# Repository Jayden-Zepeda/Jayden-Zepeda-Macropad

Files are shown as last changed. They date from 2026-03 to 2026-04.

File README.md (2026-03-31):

# ZepedaPad

> A custom 14-key macropad with dual rotary encoders, per-key RGB lighting, and an OLED display — built on the Seeed XIAO RP2040 with QMK firmware.

<p align="center">
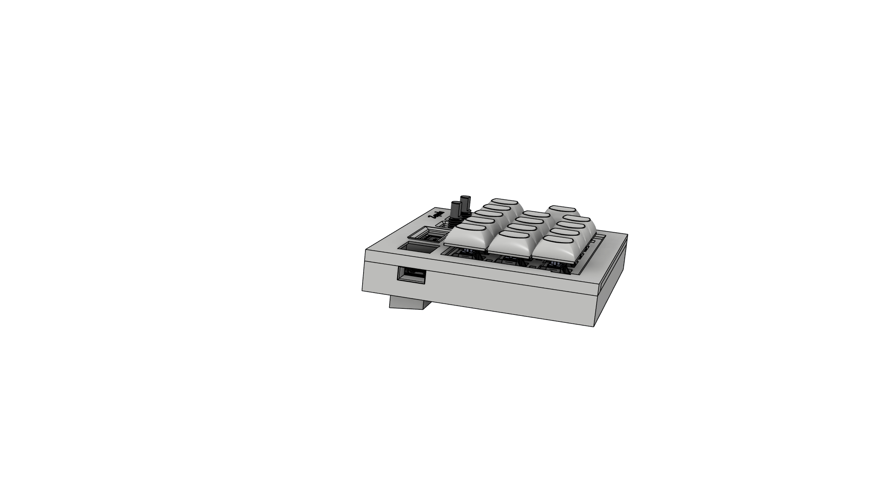
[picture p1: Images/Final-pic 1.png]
Zepeda Macropad Top View
  
</p>

---

## 📖 Overview

The **Zepeda** is a compact, handcrafted macropad designed for productivity and personalization. It features 14 MX-style switches arranged in a 3×4 grid (plus a dedicated column), two EC11 rotary encoders for scrolling or volume control, individually addressable SK6812 MINI-E RGB LEDs under every key, and a 0.91" OLED display for live feedback — all driven by a Seeed XIAO RP2040 and QMK firmware.

The key matrix is read through a **74HC165 shift register**, keeping GPIO usage minimal while supporting full anti-ghosting via 1N4148 diodes. The entire build fits inside a custom 3-part 3D-printed case secured with heatset inserts and M3 screws.

PCB is designed through KICAD and the case is designed in Autodesk Fusion-FREE.

---

## 🖼️ Screenshots

### 3D Render

<p align="center">
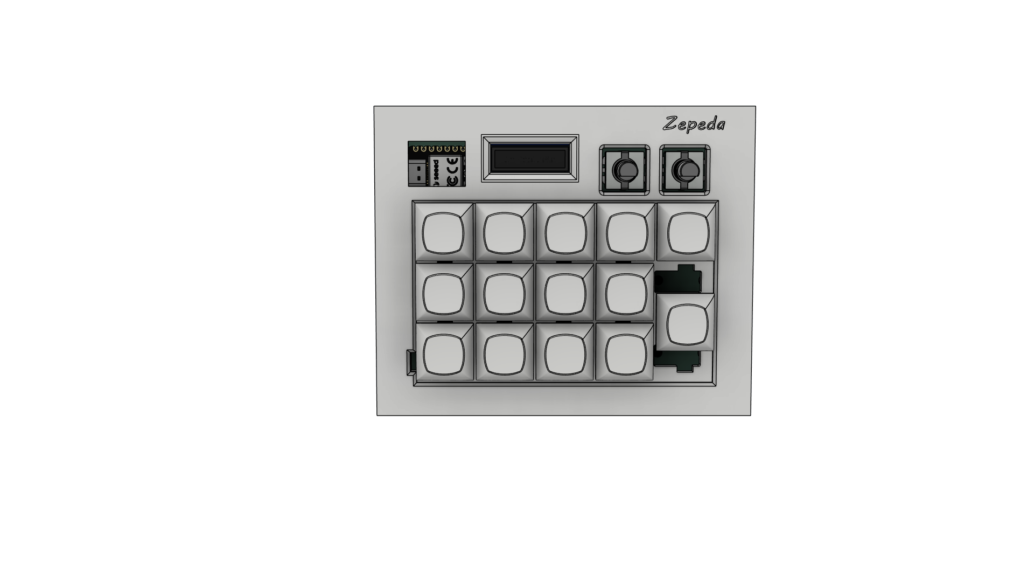
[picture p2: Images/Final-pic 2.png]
Top-down render
  
  <br/><em>Top-down view</em>
</p>

<p align="center">
  Isometric render
  <br/><em>Isometric view showing case depth and USB cutout</em>
</p>

---

### Schematic

> Full schematic showing the XIAO RP2040, 74HC165 shift register, LED chain, diode matrix, rotary encoders, and OLED connector.

<p align="center">
  Schematic
  <br/><em>KiCad schematic — macropad.kicad_sch</em>
</p>

---

### PCB Layout

<p align="center">
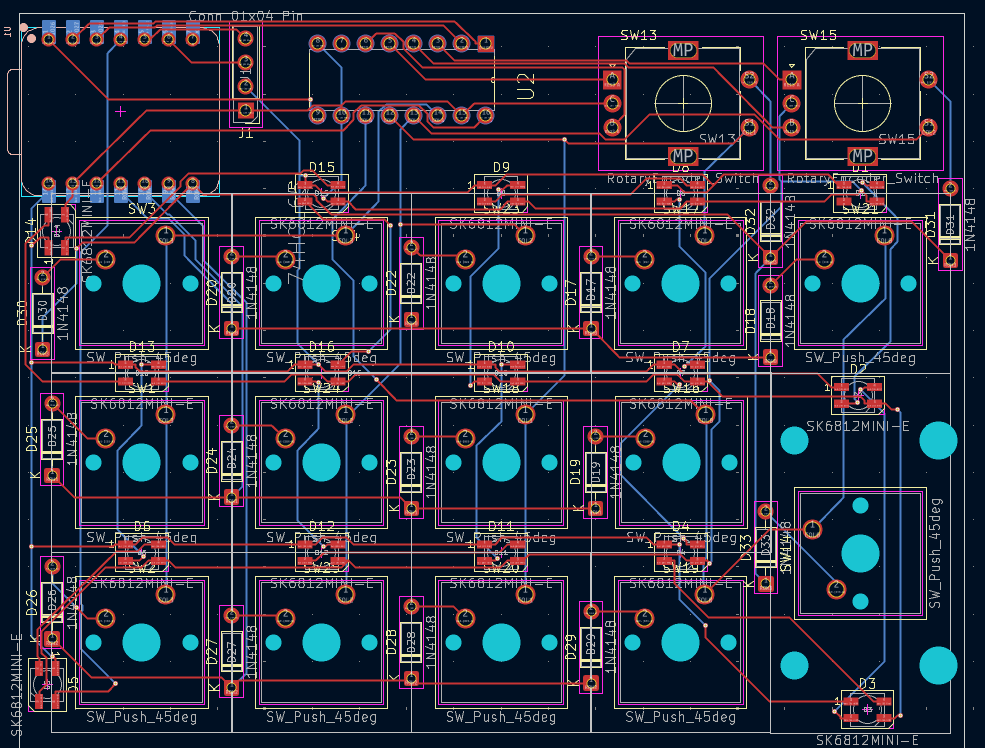
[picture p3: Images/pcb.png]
PCB Layout
  
  <br/><em>KiCad PCB layout — red/blue layers, switch footprints, and LED positions visible</em>
</p>

---

### Case

<p align="center">
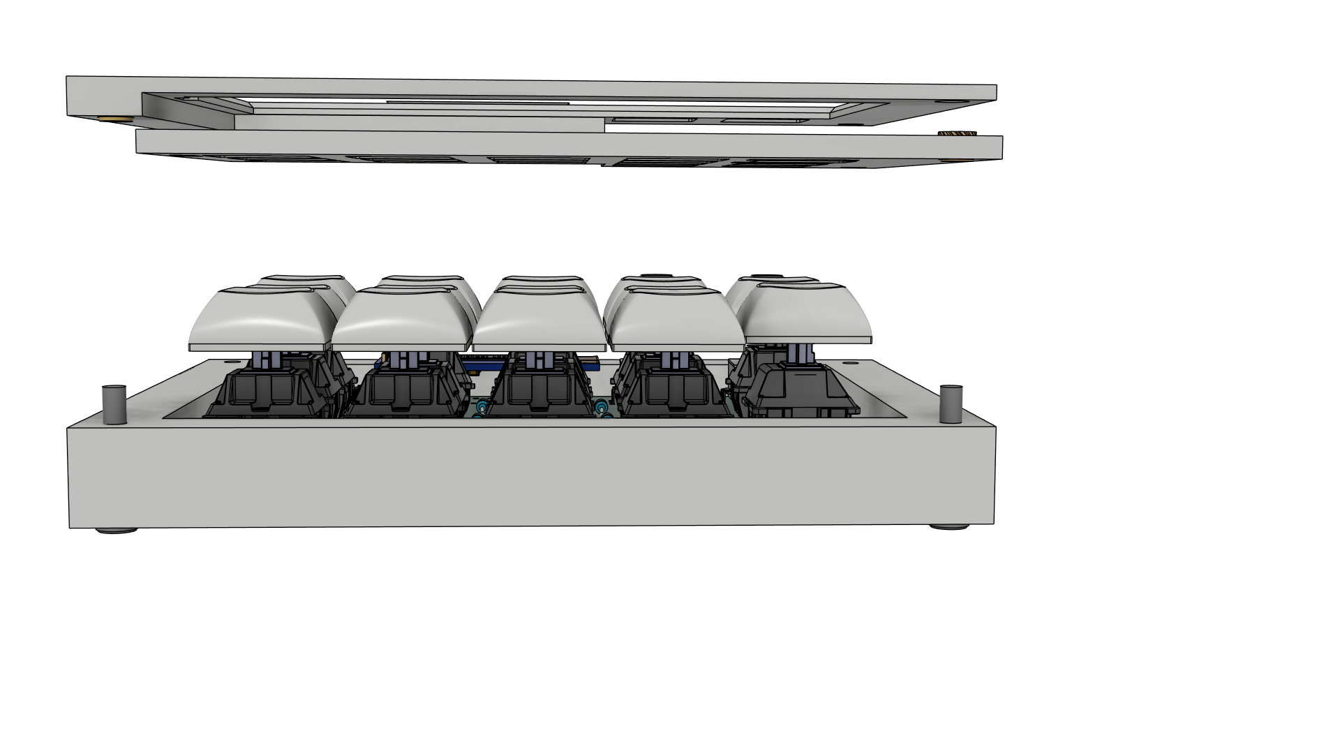
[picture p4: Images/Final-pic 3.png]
Case isometric
  
  <br/><em>3-part 3D-printed enclosure with heatset inserts. The PCB sits inside the bottom shell; the top plate exposes keycaps, encoders, and the OLED. A middle layer sandwiches everything together. Screws are enter from bottom, they go in 2mm freely and then left side screws all the way into the heatset insterts that are in the top shell while, the right side screws does a very similar thing except the heatset insterts are 1mm in the top shell and 3mm in the middle shell.</em>
</p>

The case consists of three printed parts(created in Autodesk Fusion-FREE) :
- **Bottom shell** — holds the PCB
- **Middle frame / plate** — key switch mounting plate
- **Top accent** — surrounds the OLED and encoder knobs

All three parts are secured with **4× M3×16mm screws** threading into **4× M3×5mm×4mm heatset inserts** pressed into the top/middle shell.

---

## 🧰 Bill of Materials (BOM)

| Qty | Part | Notes |
|-----|---|---|
| 1 | Seeed XIAO RP2040 | Microcontroller (unsoldered) |
| 1 | 74HC165 Shift Register | Through-hole DIP-16 |
| 16 | SK6812 MINI-E LEDs | Per-key addressable RGB |
| 16 | 1N4148 Diodes | Through-hole, for key matrix |
| 14 | MX-Style Switches | Any MX-compatible switch |
| 14 | White Blank DSA Keycaps | 1u, blank |
| 2 | EC11 Rotary Encoders | With push-click |
| 1 | 0.91" OLED Display | I2C, SSD1306 |
| 1 | 3D-Printed Case | 3 printed parts |
| 4 | M3×16mm Screws | Case assembly |
| 4 | M3×5mm×4mm Heatset Inserts | Press-fit into top/middle shell |

---

## ⚡ Firmware

This macropad runs **QMK Firmware**. The 74HC165 shift register is used to read the key matrix, and the SK6812 MINI-E LEDs are driven via QMK's RGB Matrix feature. Created a full keyboard and keymap layout from scratch. Included in firmware folder(macropad).                                    

Features:
-Copy/Paste Key: First click is copy-second is paste, with an led and OLED display to show your status.
-Mute/Unmute Key: Led and OLED display to show your status
-4 Different Layers: Base, Media, Gaming, and CFG -- w/ led status

To build and flash:

```bash
qmk compile -kb macropad -km default
qmk flash -kb macropad -km default
```

Put the XIAO RP2040 into bootloader mode by holding **BOOT** while plugging in USB (or double-tapping RST).

---

## 🔧 Build Notes

- Solder **heatset inserts first** before assembling the case
- Flash QMK firmware onto the XIAO RP2040 **before** soldering it to the board
- The LED chain is daisy-chained: DOUT of each SK6812 connects to DIN of the next
- Diodes are oriented with the **cathode (K) toward the row line** — check markings before soldering
- The 74HC165's `~PL`, `CP`, and `Q7` lines connect to GPIO26, GPIO27, and GPIO28 on the XIAO respectively

---

## 📁 Repository Structure

```
Jayden-Zepeda-Macropad/
├── pcb/               # KiCad project files (.kicad_sch, .kicad_pcb)
├── case/              # 3D print files (.step / .stl)
├── firmware/          # QMK keymap and config
├── images/            # Images
├── production/            # Files for production
└── README.md
```

---

*Made with ❤️ as part of [Hack Club's PCB program](https://hackclub.com/)*

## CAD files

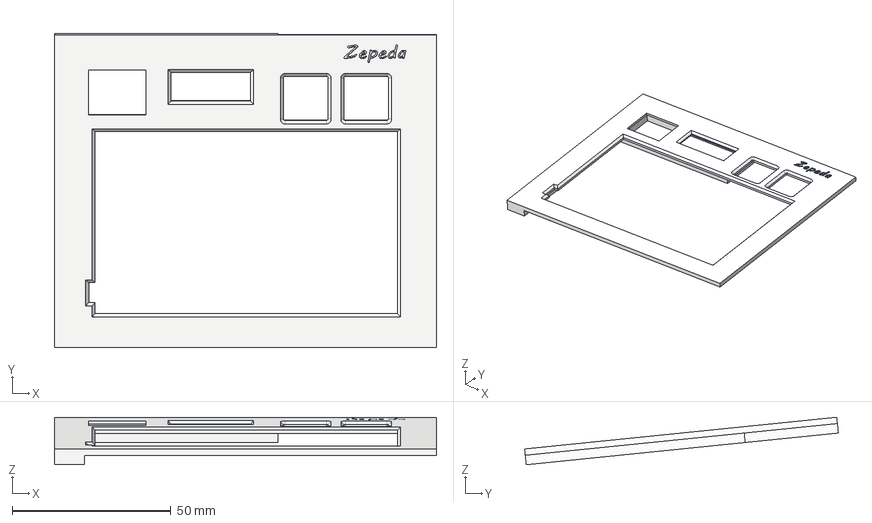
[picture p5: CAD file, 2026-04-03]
Production/Top.step
120.4 x 98.9 x 15.0 mm

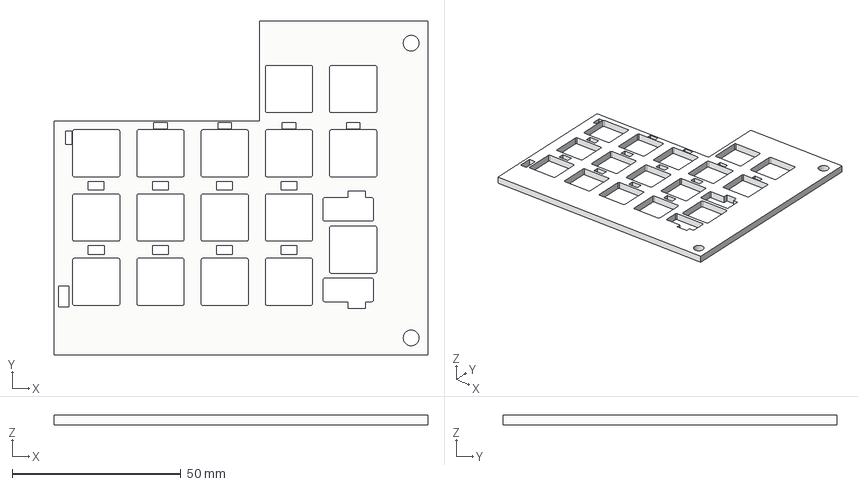
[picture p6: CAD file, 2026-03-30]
Production/Middle.step
110.9 x 98.9 x 3.00 mm

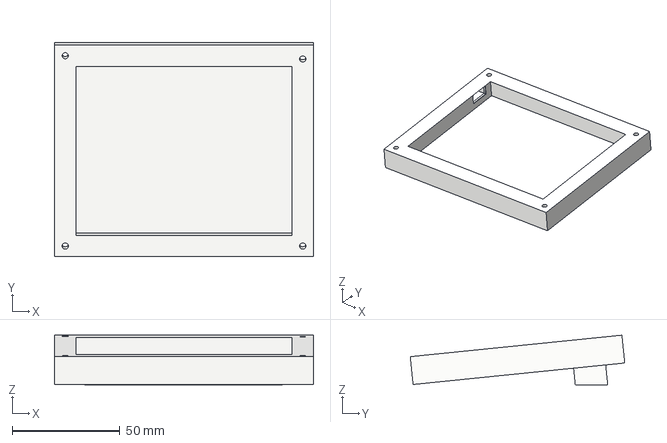
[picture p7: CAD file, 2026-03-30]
Production/Bottom.step
120.4 x 99.7 x 23.1 mm

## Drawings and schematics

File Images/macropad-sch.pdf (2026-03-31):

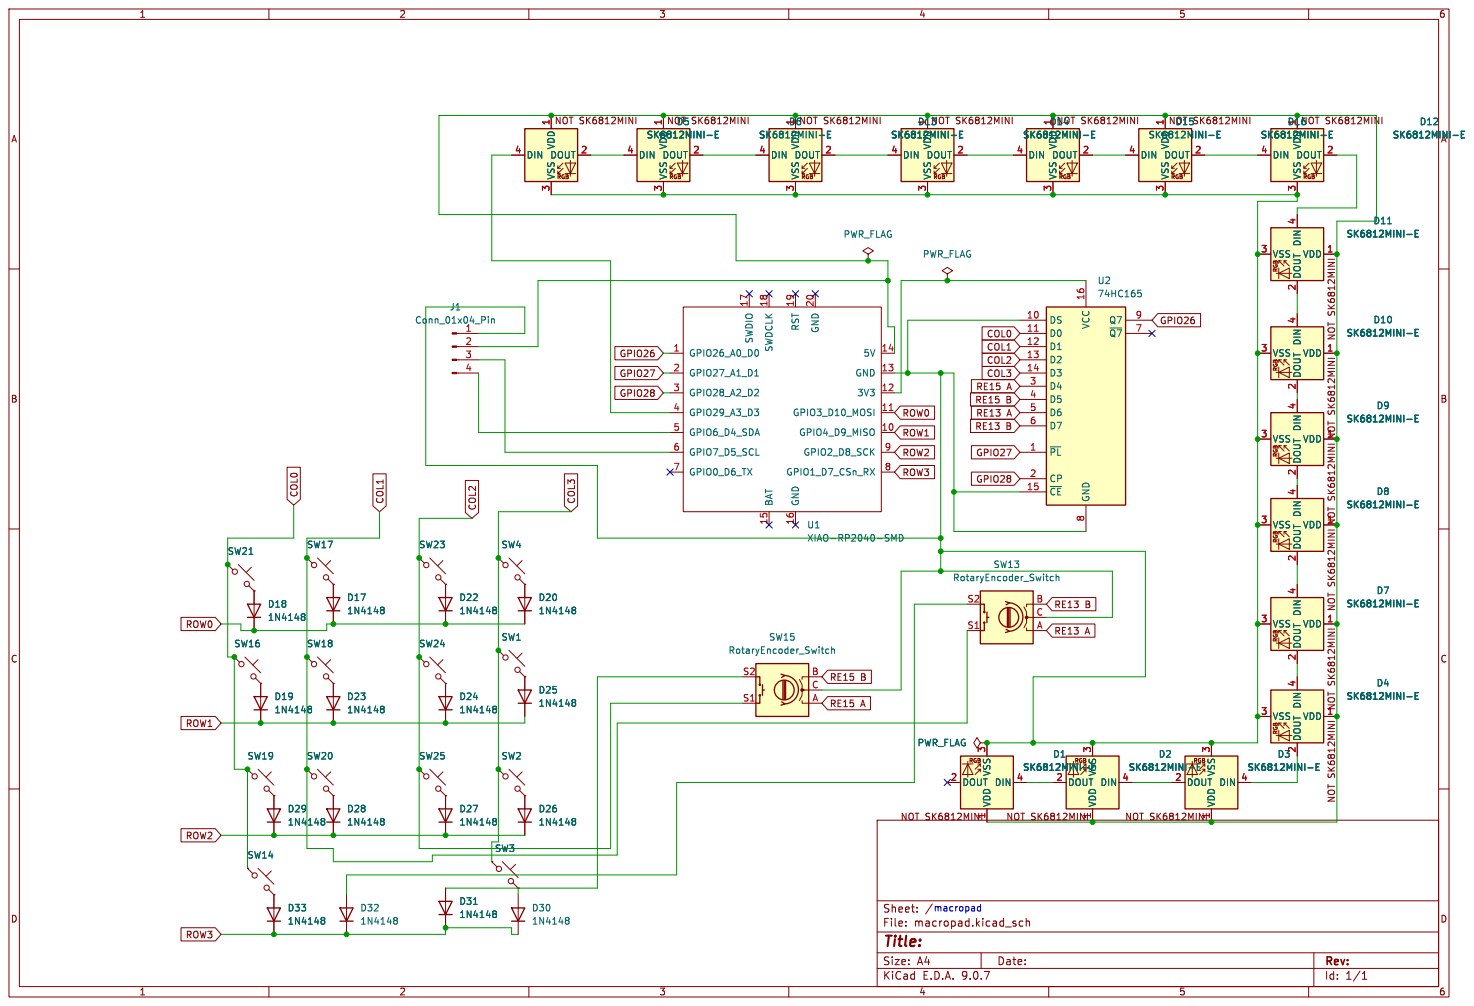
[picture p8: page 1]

3 DOUT 2 D6 SK6812MINI-E GPIO26_A0_D0 1 GPIO27_A1_D1 2 GPIO28_A2_D2 3 GPIO29_A3_D3 4 GPIO6_D4_SDA 5 GPIO7_D5_SCL 6 GPIO0_D6_TX 7 SWDIO 17 SWDCLK 18 BAT 15 RST 19 GND 16 GND 20

3 DOUT 2 D12 SK6812MINI-E RGB NOT SK6812MINI DIN

Id: 1/1 Title: File: macropad.kicad_sch Sheet: / PWR_FLAG

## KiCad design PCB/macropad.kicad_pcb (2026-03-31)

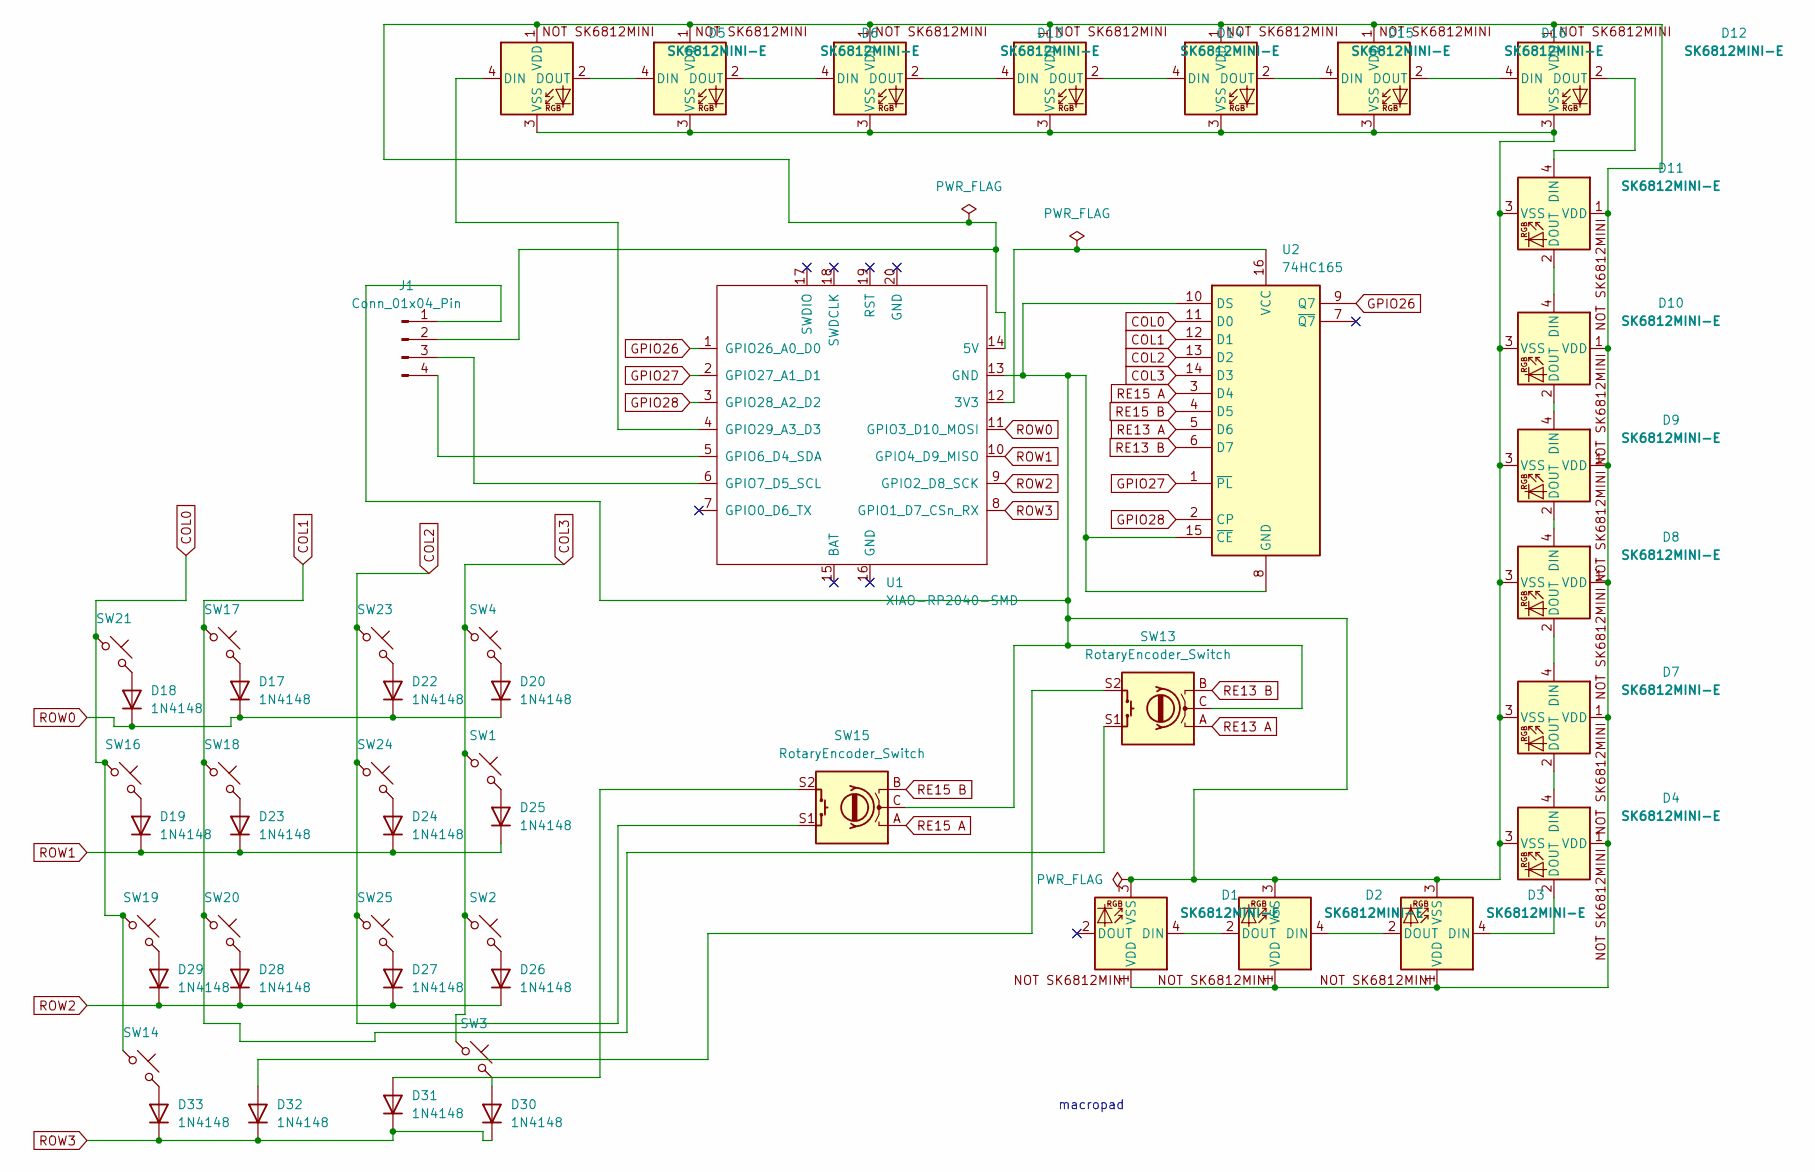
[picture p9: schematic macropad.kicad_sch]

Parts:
D1, D2, D3, D4, D5, D6, D7, D8, D9, D10, D11, D12, D13, D14, D15, D16: SK6812MINI-E; LED_SK6812MINI_PLCC4_3.5x3.5mm_P1.75mm
D17, D18, D19, D20, D22, D23, D24, D25, D26, D27, D28, D29, D30, D31, D32, D33: 1N4148; D_DO-35_SOD27_P7.62mm_Horizontal
J1: Conn_01x04_Pin; PinHeader_1x04_P2.54mm_Vertical
SW1, SW2, SW3, SW4, SW16, SW17, SW18, SW19, SW20, SW21, SW23, SW24, SW25: SW_Push_45deg; SW_Cherry_MX_1.00u_PCB
SW13, SW15: RotaryEncoder_Switch; RotaryEncoder_Alps_EC11E-Switch_Vertical_H20mm
SW14: SW_Push_45deg; SW_Cherry_MX_2.00u_PCB
U1: XIAO-RP2040-SMD; XIAO-RP2040-DIP
U2: 74HC165; DIP254P762X420-16

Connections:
COL0: SW14.1, SW16.1, SW19.1, SW21.1, U2.11 (D0)
COL1: SW13.S1, SW17.1, SW18.1, SW20.1, U2.12 (D1)
COL2: SW15.S1, SW23.1, SW24.1, SW25.1, U2.13 (D2)
COL3: SW1.1, SW2.1, SW3.1, SW4.1, U2.14 (D3)
GPIO26: U1.1 (GPIO26_A0_D0), U2.9 (Q7)
GPIO27: U1.2 (GPIO27_A1_D1), U2.1 (~PL)
GPIO28: U1.3 (GPIO28_A2_D2), U2.2 (CP)
unnamed: D1.4 (DIN), D2.2 (DOUT)
unnamed: D1.1 (VDD), D2.1 (VDD), D3.1 (VDD), D4.1 (VDD), D5.1 (VDD), D6.1 (VDD), D7.1 (VDD), D8.1 (VDD), D9.1 (VDD), D10.1 (VDD), D11.1 (VDD), D12.1 (VDD), D13.1 (VDD), D14.1 (VDD), D15.1 (VDD), D16.1 (VDD), J1.2, U1.14 (5V)
unnamed: D1.3 (VSS), D2.3 (VSS), D3.3 (VSS), D4.3 (VSS), D5.3 (VSS), D6.3 (VSS), D7.3 (VSS), D8.3 (VSS), D9.3 (VSS), D10.3 (VSS), D11.3 (VSS), D12.3 (VSS), D13.3 (VSS), D14.3 (VSS), D15.3 (VSS), D16.3 (VSS), J1.1, SW13.C, SW15.C, U1.13 (GND), U2.8 (GND), U2.10 (DS), U2.15 (~CE)
unnamed: D2.4 (DIN), D3.2 (DOUT)
unnamed: D3.4 (DIN), D4.2 (DOUT)
unnamed: D4.4 (DIN), D7.2 (DOUT)
unnamed: D5.4 (DIN), U1.4 (GPIO29_A3_D3)
unnamed: D5.2 (DOUT), D6.4 (DIN)
unnamed: D7.4 (DIN), D8.2 (DOUT)
unnamed: D8.4 (DIN), D9.2 (DOUT)
unnamed: D10.4 (DIN), D11.2 (DOUT)
unnamed: D9.4 (DIN), D10.2 (DOUT)
unnamed: D11.4 (DIN), D12.2 (DOUT)
unnamed: D12.4 (DIN), D16.2 (DOUT)
unnamed: D6.2 (DOUT), D13.4 (DIN)
unnamed: D13.2 (DOUT), D14.4 (DIN)
unnamed: D14.2 (DOUT), D15.4 (DIN)
unnamed: D15.2 (DOUT), D16.4 (DIN)
unnamed: D17.2 (A), SW17.2
unnamed: D18.2 (A), SW21.2
unnamed: D19.2 (A), SW16.2
unnamed: D20.2 (A), SW4.2
unnamed: D22.2 (A), SW23.2
unnamed: D23.2 (A), SW18.2
unnamed: D24.2 (A), SW24.2
unnamed: D25.2 (A), SW1.2
unnamed: D26.2 (A), SW2.2
unnamed: D27.2 (A), SW25.2
unnamed: D28.2 (A), SW20.2
unnamed: D29.2 (A), SW19.2
unnamed: D30.2 (A), SW3.2
unnamed: D31.2 (A), SW15.S2
unnamed: D32.2 (A), SW13.S2
unnamed: D33.2 (A), SW14.2
unnamed: J1.3, U1.6 (GPIO7_D5_SCL)
unnamed: J1.4, U1.5 (GPIO6_D4_SDA)
unnamed: U1.12 (3V3), U2.16 (VCC)
RE13 A: SW13.A, U2.5 (D6)
RE13 B: SW13.B, U2.6 (D7)
RE15 A: SW15.A, U2.3 (D4)
RE15 B: SW15.B, U2.4 (D5)
ROW0: D17.1 (K), D18.1 (K), D20.1 (K), D22.1 (K), U1.11 (GPIO3_D10_MOSI)
ROW1: D19.1 (K), D23.1 (K), D24.1 (K), D25.1 (K), U1.10 (GPIO4_D9_MISO)
ROW2: D26.1 (K), D27.1 (K), D28.1 (K), D29.1 (K), U1.9 (GPIO2_D8_SCK)
ROW3: D30.1 (K), D31.1 (K), D32.1 (K), D33.1 (K), U1.8 (GPIO1_D7_CSn_RX)

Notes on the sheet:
macropad

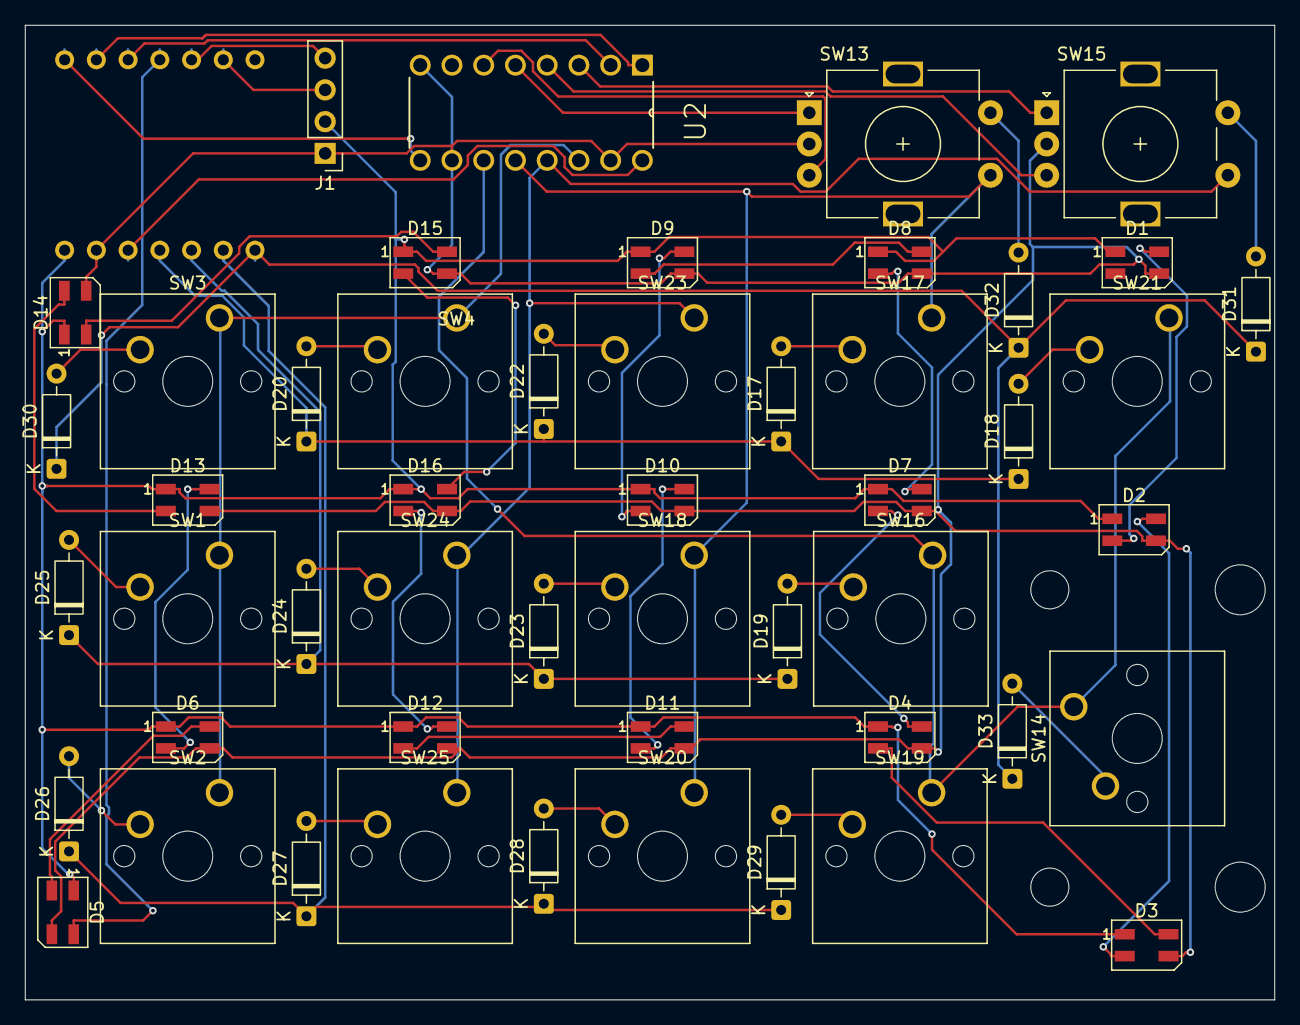
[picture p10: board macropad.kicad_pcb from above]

Board: 2 copper layers, 100.0 x 78.0 mm, 51 parts (1 on the bottom side), 52 nets.

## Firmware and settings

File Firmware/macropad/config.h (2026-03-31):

#pragma once

// ── Matrix ────────────────────────────────────────────────────────────────────
#define MATRIX_ROWS 4
#define MATRIX_COLS 4
#define MATRIX_ROW_PINS { GP3, GP4, GP2, GP1 }

// ── 74HC165 shift register ────────────────────────────────────────────────────
//   GP27=~PL(latch)  GP28=CP(clock)  GP26=Q7(data)
//   Bits: [7]=ENC0-B [6]=ENC0-A [5]=ENC1-B [4]=ENC1-A [3]=COL3 [2]=COL2 [1]=COL1 [0]=COL0
#define SHIFT_REG_PL   GP27
#define SHIFT_REG_CLK  GP28
#define SHIFT_REG_DATA GP26

// ── Encoders ──────────────────────────────────────────────────────────────────
#define NUM_ENCODERS       2
#define ENCODER_RESOLUTION 4

// ── Timings ───────────────────────────────────────────────────────────────────
#define DEBOUNCE     5
#define TAPPING_TERM 200

// ── I2C (for OLED — connects via J1: GP6=SDA, GP7=SCL) ───────────────────────
#define I2C_DRIVER   I2CD1
#define I2C1_SDA_PIN GP6
#define I2C1_SCL_PIN GP7

// ── OLED (SSD1306 128x32) ─────────────────────────────────────────────────────
#define OLED_DISPLAY_128X32
#define OLED_TIMEOUT     60000   // turn off after 60s of no activity (ms)
#define OLED_BRIGHTNESS  200

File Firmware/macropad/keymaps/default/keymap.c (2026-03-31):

#include QMK_KEYBOARD_H

// ═══════════════════════════════════════════════════════════════════════════════
//  MACROPAD KEYMAP + OLED
// ═══════════════════════════════════════════════════════════════════════════════
//
//  OLED (128x32, connects to J1 on the board via GP6=SDA / GP7=SCL):
//
//   ┌─────────────────────────────────────────┐
//   │ PRODUCTIVITY            52 wpm           │  layer name + WPM
//   │ VOL  [████████░░]  80%  ♪               │  volume bar + speaker icon
//   │ MIC  [ LIVE  ]   CLIP  [READY]          │  mic & clipboard status
//   │ Undo  Redo   Cut   Copy/Paste            │  key hints for current layer
//   └─────────────────────────────────────────┘
//
//  HOW TO CUSTOMIZE THE OLED
//  ─────────────────────────
//  • Change what shows on each line in oled_task_user() below.
//  • Each line uses oled_write() / oled_write_P() / oled_write_ln_P().
//  • oled_set_cursor(col, row) moves position (col=0-20, row=0-3).
//  • Use PSTR("text") for string literals to save RAM.
//  • Volume bar width = VOL_BAR_WIDTH (default 10 chars). Change freely.
//  • Starting volume = VOL_START (0-100). Macropad tracks from here.
//
// ═══════════════════════════════════════════════════════════════════════════════

// ── Layers ────────────────────────────────────────────────────────────────────
enum layers { BASE, MEDIA, GAME, CFG };

// ── Custom keycodes ───────────────────────────────────────────────────────────
enum custom_keycodes {
    CP_KEY = SAFE_RANGE,
    MIC_KEY,
    LNXT,
};

// ── Shortcut aliases ──────────────────────────────────────────────────────────
#define S_UNDO  LCTL(KC_Z)
#define S_REDO  LCTL(KC_Y)
#define S_CUT   LCTL(KC_X)
#define S_SAVE  LCTL(KC_S)
#define S_SALL  LCTL(KC_A)
#define S_FIND  LCTL(KC_F)
#define S_REPL  LCTL(KC_H)
#define S_NTAB  LCTL(KC_T)
#define S_CTAB  LCTL(KC_W)
#define S_ALTT  LALT(KC_TAB)
#define S_PWIN  LGUI(LSFT(KC_S))
#define S_LOCK  LGUI(KC_L)
#define S_DESK  LGUI(KC_D)
#define S_WTAB  LGUI(KC_TAB)
#define S_TASK  LCTL(LSFT(KC_ESC))
#define S_PREV  KC_MPRV
#define S_PLAY  KC_MPLY
#define S_NEXT  KC_MNXT
#define S_STOP  KC_MSTP
#define S_MUTE  KC_MUTE
#define S_VOLU  KC_VOLU
#define S_VOLD  KC_VOLD
#define S_BRIU  KC_BRIU
#define S_BRID  KC_BRID
#define S_DCMUT LCTL(LSFT(KC_M))
#define S_DCDEF LCTL(LSFT(KC_D))
#define S_CLIP  LGUI(LALT(KC_G))
#define S_RECRD LGUI(LALT(KC_R))
#define S_GBAR  LGUI(KC_G)
#define S_OBS1  KC_F13
#define S_OBS2  KC_F14
#define S_OBS3  KC_F15
#define S_OBSST KC_F16


// ═══════════════════════════════════════════════════════════════════════════════
//  STATE
// ═══════════════════════════════════════════════════════════════════════════════

static bool    clipboard_full = false;
static bool    mic_muted      = false;
static bool    spk_muted      = false;   // speaker mute state
static bool    recording      = false;   // OBS/Game Bar recording state

// Volume is tracked locally starting from VOL_START.
// Every volume key press adjusts by VOL_STEP.
// ↓ change VOL_START if your system volume is different when you first plug in
#define VOL_START  50    // assumed starting volume (0-100)
#define VOL_STEP    2    // how much each key press changes volume
#define VOL_BAR_WIDTH 10 // number of characters in the volume bar

static int8_t  vol_level = VOL_START;   // 0-100


bool process_record_user(uint16_t keycode, keyrecord_t *record) {
    switch (keycode) {

        case CP_KEY:
            if (record->event.pressed) {
                if (!clipboard_full) {
                    tap_code16(LCTL(KC_C));
                    clipboard_full = true;
                } else {
                    tap_code16(LCTL(KC_V));
                    clipboard_full = false;
                }
            }
            return false;

        case MIC_KEY:
            if (record->event.pressed) {
                tap_code16(S_DCMUT);
                mic_muted = !mic_muted;
            }
            return false;

        case LNXT:
            if (record->event.pressed) {
                uint8_t next = (get_highest_layer(layer_state) + 1) % 4;
                layer_clear();
                if (next != BASE) layer_on(next);
            }
            return false;

        // Track volume key presses to update the OLED bar
        case S_VOLU:
            if (record->event.pressed) {
                vol_level += VOL_STEP;
                if (vol_level > 100) vol_level = 100;
                spk_muted = false;
            }
            return true;   // still send the key

        case S_VOLD:
            if (record->event.pressed) {
                vol_level -= VOL_STEP;
                if (vol_level < 0) vol_level = 0;
                spk_muted = false;
            }
            return true;

        case S_MUTE:
            if (record->event.pressed) spk_muted = !spk_muted;
            return true;

        // Track OBS/Game Bar record state
        case S_RECRD:
            if (record->event.pressed) recording = !recording;
            return true;
    }
    return true;
}


// ═══════════════════════════════════════════════════════════════════════════════
//  OLED
// ═══════════════════════════════════════════════════════════════════════════════

oled_rotation_t oled_init_user(oled_rotation_t rotation) {
    // Change to OLED_ROTATION_180 if your OLED is upside down
    return OLED_ROTATION_0;
}

// Draw a horizontal bar — filled_chars out of total_chars
static void draw_bar(uint8_t filled, uint8_t total) {
    oled_write_char('[', false);
    for (uint8_t i = 0; i < total; i++) {
        // Use block char (0xFF = full block in most SSD1306 fonts)
        oled_write_char(i < filled ? 0xFF : 0xBB, false);
    }
    oled_write_char(']', false);
}

// Write a right-aligned number in a fixed-width field (width chars)
static void write_num(int8_t val, uint8_t width) {
    char buf[8];
    snprintf(buf, sizeof(buf), "%*d", width, val);
    oled_write(buf, false);
}
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

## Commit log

2026-03-30 Firmware and Production is left
    [BASE.step, Plate.step, Top Plate.step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]
2026-03-30 Almost done- REVIEW NEEDED
    [Bottom.step, Middle.step, Top.step]
2026-03-31 CHECK NEEDED
    [BASE.step, Plate.step, Top Plate.step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]
